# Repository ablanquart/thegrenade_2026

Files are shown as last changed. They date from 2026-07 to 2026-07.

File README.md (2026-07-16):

# The Grenade 2026 - An MRF101 40m AM Linear Amplifier
## USB-C Powered - 10W Carrier / 40W PEP - SMA Connectors

A bench-oriented 40-meter (7.0–7.3 MHz) AM linear amplifier built around a push-pull
pair of NXP **MRF101AN/MRF101BN** LDMOS transistors — powered from a standard 100 W
USB-C PD supply. Designed for experimental use under an FCC Part 5 license and
general amateur use on 40m.

**10 W carrier / 40 W PEP · 50 Ω in/out · runs from a laptop brick · absorptive harmonic termination**

## Features

- **USB-C powered**: negotiates 20 V / 5 A from any 100 W PD supply via a CH224K sink
  controller, then boosts to 48 V with an LM5122 synchronous boost converter.
- **Dual power path**: the boost output and a 48 V bench input are diode-ORed onto the
  main VDD rail — plug in whichever you have; both is fine.
- **Absorptive harmonic termination**: a high-pass diplexer branch dumps everything the
  output low-pass filter rejects into a 50 Ω / 6 W resistive load instead of reflecting
  it back into the PA drains. The transistors see a resistive load at all frequencies.
- **Interlocked bring-up**: the driver supply (LM2596HV buck) is enabled only after PD
  negotiation succeeds, or manually via a force-enable jumper (J5).
- **Status LEDs**: green = PD negotiated and boost alive; amber = main 48 V rail present.
- Temperature-tracked gate bias for the output pair.
- 7-element Chebyshev low-pass output filter, 7.5 MHz cutoff.

## Repository layout

```
├── mrf101_40m_pa_usbpd.kicad_pro   # KiCad project
├── mrf101_40m_pa_usbpd.kicad_sch   # Schematic
├── mrf101_40m_pa_usbpd.kicad_pcb   # Board (220 × 130 mm, 2-layer)
├── BOM_mrf101_40m_pa_usbpd.csv     # Bill of materials (grouped, with quantities)
├── fab_usbpd/                      # Gerbers, drill files, paste layers
├── docs/
│   ├── USER_GUIDE.md               # Setup and operation
│   └── SERVICE_MANUAL.md           # Theory of operation, component reference, test points
├── CHANGELOG.md
├── LICENSE                         # CERN-OHL-S v2
└── README.md
```

## Quick start

1. Bolt the board to a heatsink — the MRF101 pair **requires** one (TO-220 tab-down).
2. Connect a 50 Ω dummy load or antenna system to **J2 (RF OUT)**. Never key without a load.
3. Power: plug a 100 W USB-C PD supply into **J4**, or 48 V bench into **J3**.
4. Green LED (D7) = PD negotiated; amber LED (D8) = 48 V rail up.
5. Apply drive (≈1 W nominal) to **J1 (RF IN)**.

Full setup, bias adjustment, and first-power-up procedures are in
[docs/USER_GUIDE.md](docs/USER_GUIDE.md). Circuit theory, a complete component function
reference, and oscilloscope test points are in
[docs/SERVICE_MANUAL.md](docs/SERVICE_MANUAL.md).

## Bill of materials

The complete grouped BOM is [`BOM_mrf101_40m_pa_usbpd.csv`](BOM_mrf101_40m_pa_usbpd.csv).
Sourcing notes for the parts that matter:

| Part | Refs | Notes |
|---|---|---|
| MRF101AN + MRF101BN | Q1, Q2 | Buy the AN/BN *pair* — mirrored pinouts for layout symmetry. |
| CH224K | U3 | USB-PD sink controller, SSOP-10. |
| LM5122 | U4 | Sync boost controller, HTSSOP-20 (exposed pad). |
| LM2596HV-12 | U2 | HV variant is mandatory — input is 48 V. |
| BN-43-202, BN-43-3312 | T1, T2 | Binocular ferrite cores; wind per schematic. |
| 330 pF C0G **250 V** | C33, C34 | Diplexer series caps — voltage rating matters. |
| 390 nH, Q > 50 @ 20 MHz | L8 | 1812 air-core/ceramic, or wind 8t on a T37-6. |
| 100 Ω **3 W** 2512 | R34, R35 | The harmonic dump — do not substitute smaller. |
| USB-C 16-pin receptacle | J4 | Mid-mount, 5 A rated. |

## Regenerating fabrication files

With KiCad 10.x:

```sh
KCLI=/Applications/KiCad/KiCad.app/Contents/MacOS/kicad-cli   # adjust for your OS

$KCLI pcb export gerbers mrf101_40m_pa_usbpd.kicad_pcb -o fab_usbpd/
$KCLI pcb export drill   mrf101_40m_pa_usbpd.kicad_pcb -o fab_usbpd/ \
      --excellon-units mm --excellon-separate-th
```

Include the paste layers (F.Paste/B.Paste) if you're having a stencil made.

## Safety

This is a 40-watt RF power amplifier running on a 48-volt rail. Treat it accordingly:
hot heatsinks, RF voltage on exposed copper, and enough stored energy in the bulk
capacitors to be memorable. Operate into a proper load, within your license privileges,
and keep fingers off the output network while transmitting.

## License

This project is licensed under the **CERN Open Hardware Licence Version 2 —
Strongly Reciprocal (CERN-OHL-S v2)**. See [LICENSE](LICENSE) for the full text.

Copyright © 2026 Adam Blanquart

This source describes Open Hardware and is licensed under the CERN-OHL-S v2.
You may redistribute and modify this source and make products using it under
the terms of the CERN-OHL-S v2 (https://ohwr.org/cern_ohl_s_v2.txt).

This source is distributed WITHOUT ANY EXPRESS OR IMPLIED WARRANTY, INCLUDING
OF MERCHANTABILITY, SATISFACTORY QUALITY AND FITNESS FOR A PARTICULAR PURPOSE.
Please see the CERN-OHL-S v2 for applicable conditions.

Source location: https://github.com/ablanquart/thegrenade_2026/

As per CERN-OHL-S v2 section 4.1, any product you make from this design should
carry a reference back to the source location above.

---

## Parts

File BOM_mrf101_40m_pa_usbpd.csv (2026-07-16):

Refs | Value | Footprint | Qty
C1,C2,C7-C9,C14,C19,C22,C32 | 100nF | Capacitor_SMD:C_0805_2012Metric | 9
C3,C6 | 510pF | Capacitor_SMD:C_1206_3216Metric | 2
C4,C5 | 910pF | Capacitor_SMD:C_1206_3216Metric | 2
C10 | 1uF 100V | Capacitor_SMD:C_1206_3216Metric | 1
C11 | 100uF 63V | Capacitor_THT:CP_Radial_D8.0mm_P3.50mm | 1
C12 | 220uF 25V | Capacitor_THT:CP_Radial_D8.0mm_P3.50mm | 1
C13 | 10uF 25V | Capacitor_SMD:C_1206_3216Metric | 1
C20 | 10nF | Capacitor_SMD:C_0805_2012Metric | 1
C21 | 100pF | Capacitor_SMD:C_0805_2012Metric | 1
C23 | 2.2uF | Capacitor_SMD:C_1206_3216Metric | 1
C24,C25 | 22uF 63V | Capacitor_SMD:C_1210_3225Metric | 2
C26,C27 | 1000uF 63V | Capacitor_THT:CP_Radial_D10.0mm_P5.00mm | 2
C28 | 10uF 63V | Capacitor_SMD:C_1210_3225Metric | 1
C29,C30 | 22uF 25V | Capacitor_SMD:C_1210_3225Metric | 2
C31 | 1uF | Capacitor_SMD:C_0805_2012Metric | 1
C33,C34 | 330pF C0G 250V | Capacitor_SMD:C_1210_3225Metric | 2
D1 | SB560 (60V 5A) | Diode_SMD:D_SMC | 1
D3 | SS36 (60V) | Diode_SMD:D_SMA | 1
D4 | SB560 | Diode_SMD:D_SMC | 1
D6 | SMBJ24A | Diode_SMD:D_SMB | 1
D7 | green PD-OK | LED_SMD:LED_0805_2012Metric | 1
D8 | amber VDD | LED_SMD:LED_0805_2012Metric | 1
F1 | 6A | Fuse:Fuse_1812_4532Metric | 1
FLG1-FLG9 | PWR_FLAG |  | 9
J1 | SMA in | Connector_Coaxial:SMA_Molex_73251-1153_EdgeMount_Horizontal | 1
J2 | SMA out | Connector_Coaxial:SMA_Molex_73251-1153_EdgeMount_Horizontal | 1
J3 | 48V DC in | TerminalBlock:TerminalBlock_MaiXu_MX126-5.0-02P_1x02_P5.00mm | 1
J4 | USB-C PD 100W | Connector_USB:USB_C_Receptacle_HRO_TYPE-C-31-M-12 | 1
J5 | force-en | Connector_PinHeader_2.54mm:PinHeader_1x02_P2.54mm_Vertical | 1
L1,L3 | 1.51uH (19t T50-6) | Inductor_THT:L_Toroid_Vertical_L14.0mm_W6.3mm_P4.57mm_Pulse_A | 2
L2 | 1.67uH (20t T50-6) | Inductor_THT:L_Toroid_Vertical_L14.0mm_W6.3mm_P4.57mm_Pulse_A | 1
L4 | RFC 1mH | Inductor_THT:L_Toroid_Vertical_L14.0mm_W6.3mm_P4.57mm_Pulse_A | 1
L5 | 100uH | Inductor_SMD:L_12x12mm_H8mm | 1
L6 | 15uH 12A | Inductor_SMD:L_12x12mm_H8mm | 1
L7 | 2.2uH | Inductor_SMD:L_12x12mm_H4.5mm | 1
L8 | 390nH | Inductor_SMD:L_1812_4532Metric | 1
Q1 | MRF101AN | Package_TO_SOT_THT:TO-220-3_Horizontal_TabDown | 1
Q2 | MRF101BN | Package_TO_SOT_THT:TO-220-3_Horizontal_TabDown | 1
Q3 | 2N3904 | Package_TO_SOT_THT:TO-92_Inline | 1
Q4 | 2N3904 (heatsink) | Package_TO_SOT_THT:TO-92_Inline | 1
Q6 | 100V NFET | Package_TO_SOT_SMD:TO-252-2 | 1
Q7 | 100V NFET sync | Package_TO_SOT_SMD:TO-252-2 | 1
R1,R2 | 10 | Resistor_SMD:R_0805_2012Metric | 2
R3,R5,R13,R18,R20,R31 | 1k | Resistor_SMD:R_0805_2012Metric | 6
R4 | 4k7 | Resistor_SMD:R_0805_2012Metric | 1
R6,R7 | 330 | Resistor_SMD:R_2512_6332Metric | 2
R8-R10 | pad TBD | Resistor_SMD:R_0805_2012Metric | 3
R11 | 110 | Resistor_SMD:R_0805_2012Metric | 1
R12 | 8.87k | Resistor_SMD:R_0805_2012Metric | 1
R14 | 47 | Resistor_SMD:R_0805_2012Metric | 1
R19,R26,R32 | 10k | Resistor_SMD:R_0805_2012Metric | 3
R21,R22 | 100k | Resistor_SMD:R_0805_2012Metric | 2
R23 | 13k | Resistor_SMD:R_0805_2012Metric | 1
R24 | 40k2 (250kHz) | Resistor_SMD:R_0805_2012Metric | 1
R25 | 49k9 | Resistor_SMD:R_0805_2012Metric | 1
R27 | 590k | Resistor_SMD:R_0805_2012Metric | 1
R28 | 15k (50V) | Resistor_SMD:R_0805_2012Metric | 1
R29 | 5m | Resistor_SMD:R_2512_6332Metric | 1
R33 | 10k (FPWM) | Resistor_SMD:R_0805_2012Metric | 1
R34,R35 | 100 3W | Resistor_SMD:R_2512_6332Metric | 2
R36 | 6k8 | Resistor_SMD:R_0805_2012Metric | 1
R37 | 15k | Resistor_SMD:R_1206_3216Metric | 1
RV1 | 10k bias adj | Potentiometer_THT:Potentiometer_Bourns_3296W_Vertical | 1
T1 | 1:4 balun (BN-43-202) | linear_amp:Xfmr_Binocular_BN43-202_5pin | 1
T2 | 4:1 (BN-43-3312) | linear_amp:Xfmr_Binocular_BN43-3312_5pin | 1
U1 | PGA-103+ | linear_amp:PGA_103_MMIC | 1
U2 | LM2596HV-ADJ | Package_TO_SOT_THT:TO-220-5_Vertical | 1
U3 | CH224K | Package_SO:SSOP-10-1EP_3.9x4.9mm_P1mm_EP2.1x3.3mm | 1
U4 | LM5122 | Package_SO:HTSSOP-20-1EP_4.4x6.5mm_P0.65mm_EP3.4x6.5mm | 1

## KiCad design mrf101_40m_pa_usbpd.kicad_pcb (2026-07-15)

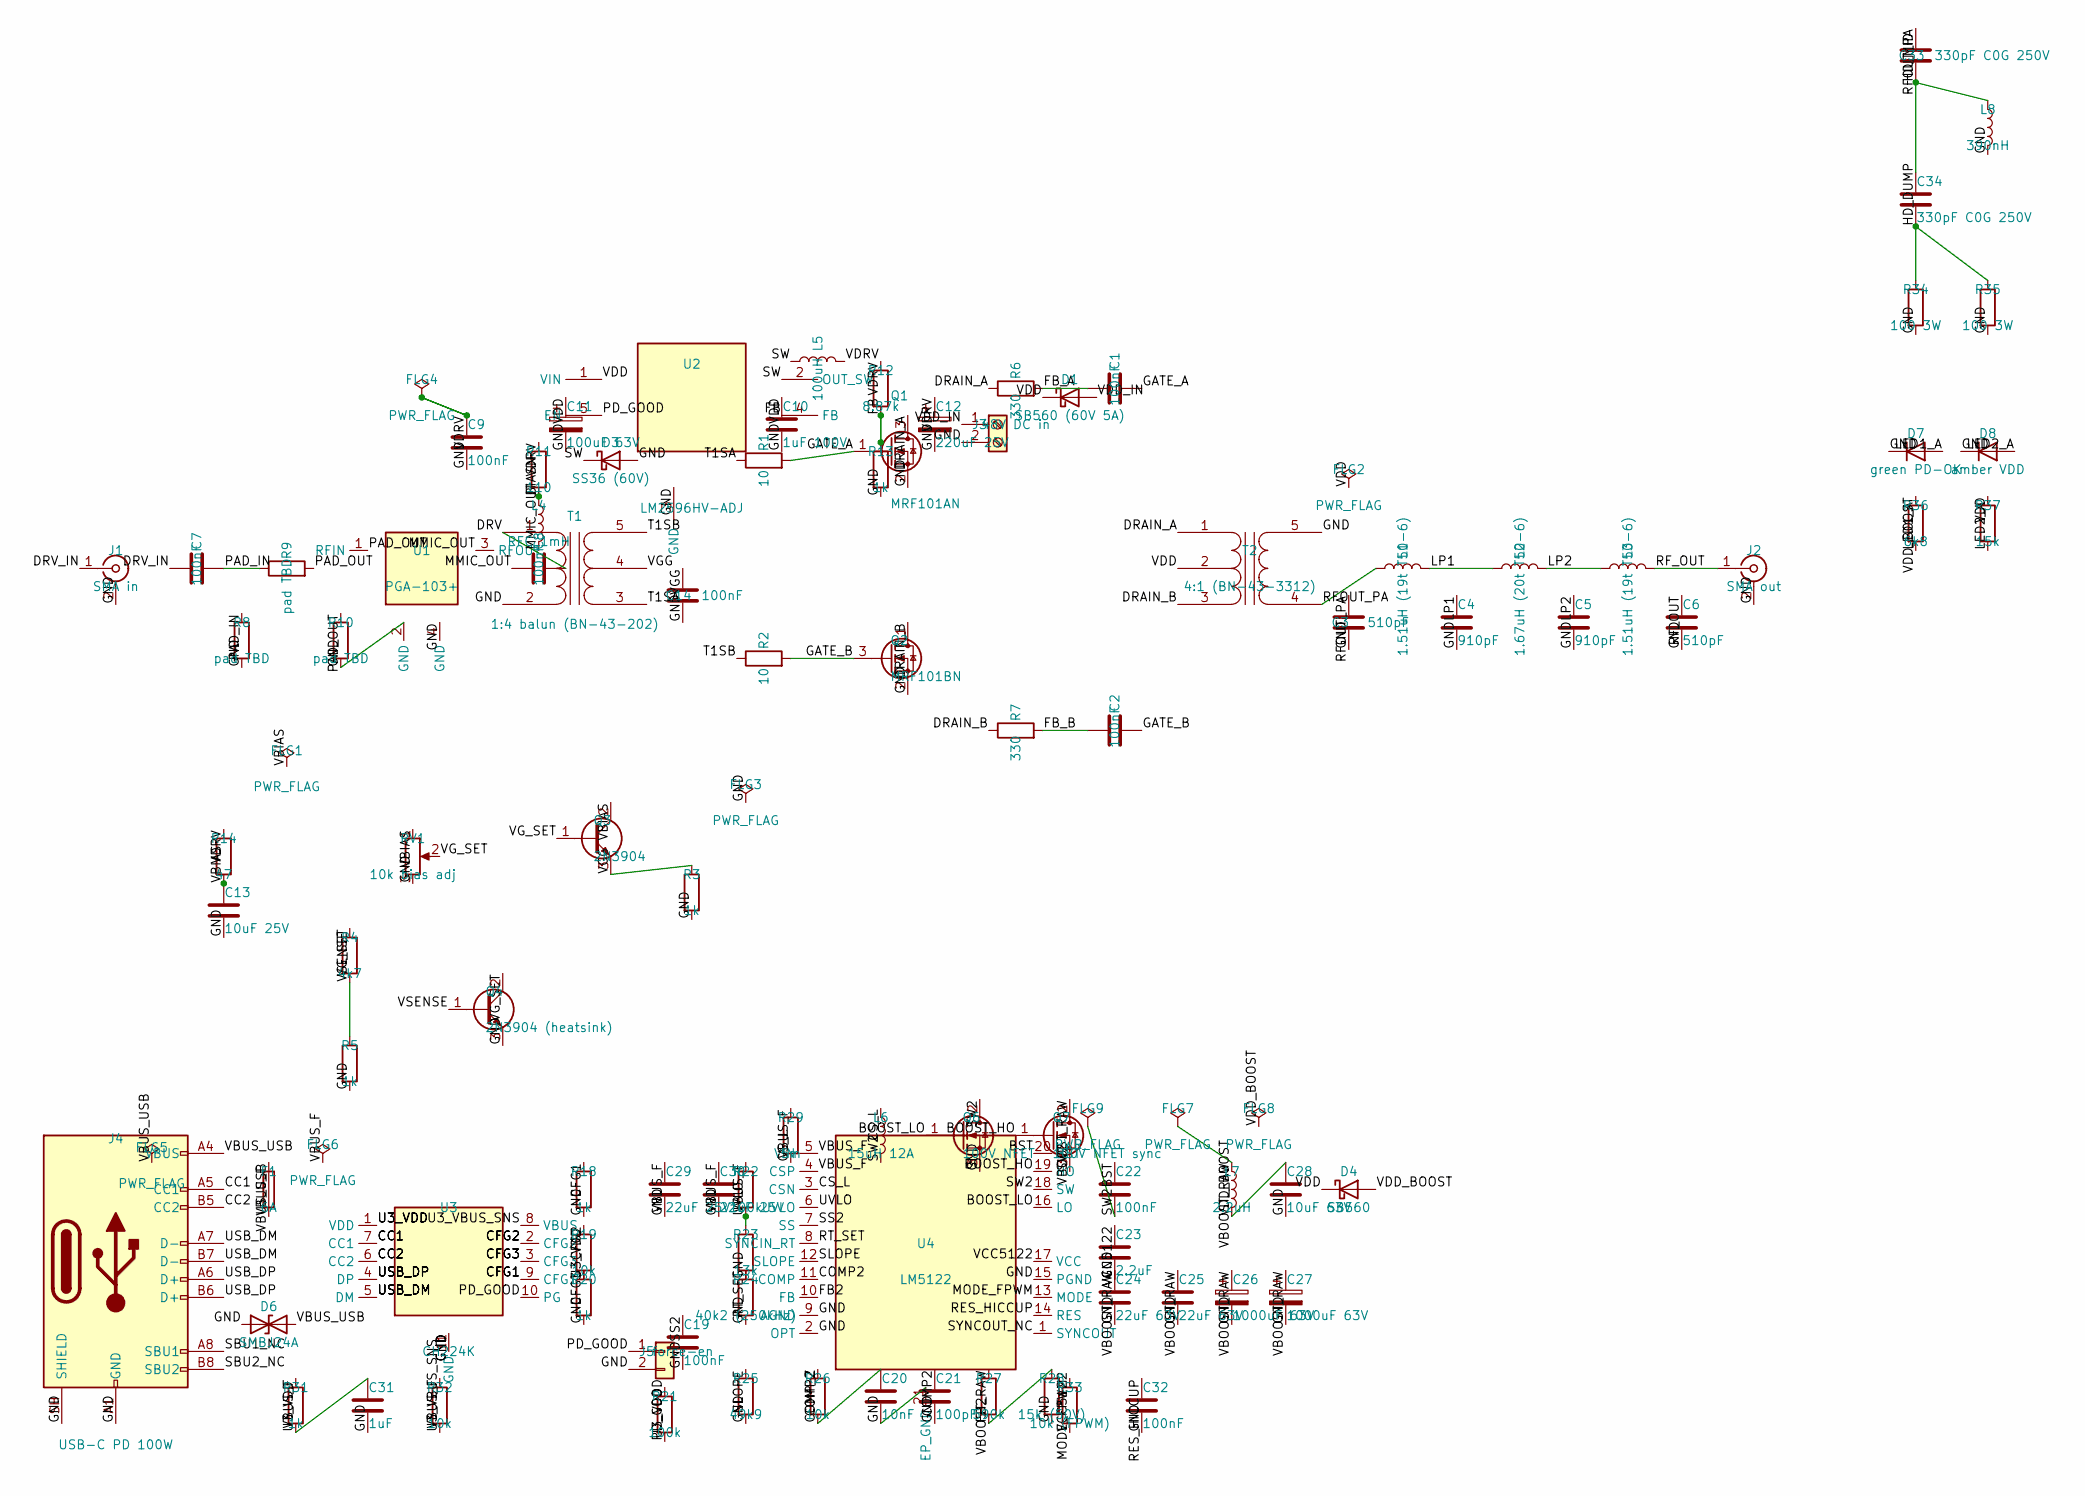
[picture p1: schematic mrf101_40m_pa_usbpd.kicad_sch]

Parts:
C1, C2, C7, C8, C9, C14, C19, C22, C32: 100nF; C_0805_2012Metric
C3, C6: 510pF; C_1206_3216Metric
C4, C5: 910pF; C_1206_3216Metric
C10: 1uF 100V; C_1206_3216Metric
C11: 100uF 63V; CP_Radial_D8.0mm_P3.50mm
C12: 220uF 25V; CP_Radial_D8.0mm_P3.50mm
C13: 10uF 25V; C_1206_3216Metric
C20: 10nF; C_0805_2012Metric
C21: 100pF; C_0805_2012Metric
C23: 2.2uF; C_1206_3216Metric
C24, C25: 22uF 63V; C_1210_3225Metric
C26, C27: 1000uF 63V; CP_Radial_D10.0mm_P5.00mm
C28: 10uF 63V; C_1210_3225Metric
C29, C30: 22uF 25V; C_1210_3225Metric
C31: 1uF; C_0805_2012Metric
C33, C34: 330pF C0G 250V; C_1210_3225Metric
D1: SB560 (60V 5A); D_SMC
D3: SS36 (60V); D_SMA
D4: SB560; D_SMC
D6: SMBJ24A; D_SMB
D7: green PD-OK; LED_0805_2012Metric
D8: amber VDD; LED_0805_2012Metric
F1: 6A; Fuse_1812_4532Metric
FLG1, FLG2, FLG3, FLG4, FLG5, FLG6, FLG7, FLG8, FLG9: PWR_FLAG
J1: SMA in; SMA_Molex_73251-1153_EdgeMount_Horizontal
J2: SMA out; SMA_Molex_73251-1153_EdgeMount_Horizontal
J3: 48V DC in; TerminalBlock_MaiXu_MX126-5.0-02P_1x02_P5.00mm
J4: USB-C PD 100W; USB_C_Receptacle_HRO_TYPE-C-31-M-12
J5: force-en; PinHeader_1x02_P2.54mm_Vertical
L1, L3: 1.51uH (19t T50-6); L_Toroid_Vertical_L14.0mm_W6.3mm_P4.57mm_Pulse_A
L2: 1.67uH (20t T50-6); L_Toroid_Vertical_L14.0mm_W6.3mm_P4.57mm_Pulse_A
L4: RFC 1mH; L_Toroid_Vertical_L14.0mm_W6.3mm_P4.57mm_Pulse_A
L5: 100uH; L_12x12mm_H8mm
L6: 15uH 12A; L_12x12mm_H8mm
L7: 2.2uH; L_12x12mm_H4.5mm
L8: 390nH; L_1812_4532Metric
Q1: MRF101AN; TO-220-3_Horizontal_TabDown
Q2: MRF101BN; TO-220-3_Horizontal_TabDown
Q3: 2N3904; TO-92_Inline
Q4: 2N3904 (heatsink); TO-92_Inline
Q6: 100V NFET; TO-252-2
Q7: 100V NFET sync; TO-252-2
R1, R2: 10; R_0805_2012Metric
R3, R5, R13, R18, R20, R31: 1k; R_0805_2012Metric
R4: 4k7; R_0805_2012Metric
R6, R7: 330; R_2512_6332Metric
R8, R9, R10: pad TBD; R_0805_2012Metric
R11: 110; R_0805_2012Metric
R12: 8.87k; R_0805_2012Metric
R14: 47; R_0805_2012Metric
R19, R26, R32: 10k; R_0805_2012Metric
R21, R22: 100k; R_0805_2012Metric
R23: 13k; R_0805_2012Metric
R24: 40k2 (250kHz); R_0805_2012Metric
R25: 49k9; R_0805_2012Metric
R27: 590k; R_0805_2012Metric
R28: 15k (50V); R_0805_2012Metric
R29: 5m; R_2512_6332Metric
R33: 10k (FPWM); R_0805_2012Metric
R34, R35: 100 3W; R_2512_6332Metric
R36: 6k8; R_0805_2012Metric
R37: 15k; R_1206_3216Metric
RV1: 10k bias adj; Potentiometer_Bourns_3296W_Vertical
T1: 1:4 balun (BN-43-202); Xfmr_Binocular_BN43-202_5pin
T2: 4:1 (BN-43-3312); Xfmr_Binocular_BN43-3312_5pin
U1: PGA-103+; PGA_103_MMIC
U2: LM2596HV-ADJ; TO-220-5_Vertical
U3: CH224K; SSOP-10-1EP_3.9x4.9mm_P1mm_EP2.1x3.3mm
U4: LM5122; HTSSOP-20-1EP_4.4x6.5mm_P0.65mm_EP3.4x6.5mm

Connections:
BIASN: L4.1, R11.2
BOOST_HO: Q7.1 (G), U4.19 (HO)
BOOST_LO: Q6.1 (G), U4.16 (LO)
BST: C22.1, U4.20 (BST)
CC1: J4.A5 (CC1), U3.7 (CC1)
CC2: J4.B5 (CC2), U3.6 (CC2)
CFG1: R18.1, U3.9 (CFG1)
CFG2: R19.1, U3.2 (CFG2)
CFG3: R20.1, U3.3 (CFG3)
COMP2: C21.1, R26.1, U4.11 (COMP)
COMP_Z: C20.1, R26.2
CS_L: L6.1, R29.2, U4.3 (CSN)
DRAIN_A: Q1.3 (D), R6.1, T2.1 (PR1)
DRAIN_B: Q2.1 (D), R7.1, T2.3 (PR2)
DRV: C8.2, T1.1 (AA)
DRV_IN: C7.1, J1.1 (In)
FB: R12.2, R13.1, U2.4 (FB)
FB2: R27.2, R28.1, U4.10 (FB)
FB_A: C1.1, R6.2
FB_B: C2.1, R7.2
GATE_A: C1.2, Q1.1 (G), R1.2
GATE_B: C2.2, Q2.3 (G), R2.2
GND: C3.2, C4.2, C5.2, C6.2, C9.2, C10.2, C11.2, C12.2, C13.2, C14.2, C19.2, C20.2, C21.2, C23.2, C24.2, C25.2, C26.2, C27.2, C28.2, C29.2, C30.2, C31.2, C32.2, D3.2 (A), D6.1 (A1), D7.1 (K), D8.1 (K), FLG3.1, J1.2 (Ext), J2.2 (Ext), J3.2, J4.A1 (GND), J4.A12 (GND), J4.B1 (GND), J4.B12 (GND), J4.SH (SHIELD), J5.2, L8.2, Q1.2 (S), Q2.2 (S), Q4.3 (E), Q6.3 (S), R3.2, R5.2, R8.2, R10.2, R13.2, R18.2, R20.2, R23.2, R24.2, R25.2, R28.2, R34.2, R35.2, RV1.3, T1.2 (AB), T2.5 (S2), U1.2 (GND), U1.4 (GND), U2.3 (GND), U3.11 (GND), U4.2 (OPT), U4.9 (AGND), U4.15 (PGND), U4.21 (EP_GND)
HD_DUMP: C34.2, R34.1, R35.1
HD_MID: C33.2, C34.1, L8.1
LED1_A: D7.2 (A), R36.2
LED2_A: D8.2 (A), R37.2
LP1: C4.1, L1.2, L2.1
LP2: C5.1, L2.2, L3.1
MMIC_OUT: C8.1, L4.2, U1.3 (RFOUT)
MODE_FPWM: R33.1, U4.13 (MODE)
PAD_IN: C7.2, R8.1, R9.1
PAD_OUT: R9.2, R10.1, U1.1 (RFIN)
PD_GOOD: J5.1, R21.2, U2.5 (EN), U3.10 (PG)
RES_HICCUP: C32.1, U4.14 (RES)
RFOUT_PA: C3.1, C33.1, L1.1, T2.4 (S1)
RF_OUT: C6.1, J2.1 (In), L3.2
RT_SET: R24.1, U4.8 (SYNCIN_RT)
SBU1_NC: J4.A8 (SBU1)
SBU2_NC: J4.B8 (SBU2)
SLOPE: R25.1, U4.12 (SLOPE)
SS2: C19.1, U4.7 (SS)
SW: D3.1 (K), L5.1, U2.2 (OUT_SW)
SW2: C22.2, FLG9.1, L6.2, Q6.2 (D), Q7.3 (S), U4.18 (SW)
SYNCOUT_NC: U4.1 (SYNCOUT)
T1SA: R1.1, T1.3 (SA)
T1SB: R2.1, T1.5 (SB)
U3_VBUS_SNS: R32.2, U3.8 (VBUS)
U3_VDD: C31.1, R19.2, R21.1, R31.2, U3.1 (VDD)
USB_DM: J4.A7 (D-), J4.B7 (D-), U3.5 (DM)
USB_DP: J4.A6 (D+), J4.B6 (D+), U3.4 (DP)
UVLO: R22.2, R23.1, U4.6 (UVLO)
VBIAS: C13.1, FLG1.1, Q3.2 (C), R14.2, RV1.1
VBOOST_RAW: C24.1, C25.1, C26.1, C27.1, FLG7.1, L7.1, Q7.2 (D), R27.1
VBUS_F: C29.1, C30.1, F1.2, FLG6.1, R22.1, R29.1, R31.1, R32.1, U4.4 (CSP), U4.5 (VIN)
VBUS_USB: D6.2 (A2), F1.1, FLG5.1, J4.A4 (VBUS), J4.A9 (VBUS), J4.B4 (VBUS), J4.B9 (VBUS)
VCC5122: C23.1, R33.2, U4.17 (VCC)
VDD: C10.1, C11.1, D1.1 (K), D4.1 (K), FLG2.1, R37.1, T2.2 (PM), U2.1 (VIN)
VDD_BOOST: C28.1, D4.2 (A), FLG8.1, L7.2, R36.1
VDD_IN: D1.2 (A), J3.1
VDRV: C9.1, C12.1, FLG4.1, L5.2, R11.1, R12.1, R14.1
VGG: C14.1, Q3.3 (E), R3.1, T1.4 (SC)
VG_SET: Q3.1 (B), Q4.2 (C), R4.1, RV1.2
VSENSE: Q4.1 (B), R4.2, R5.1

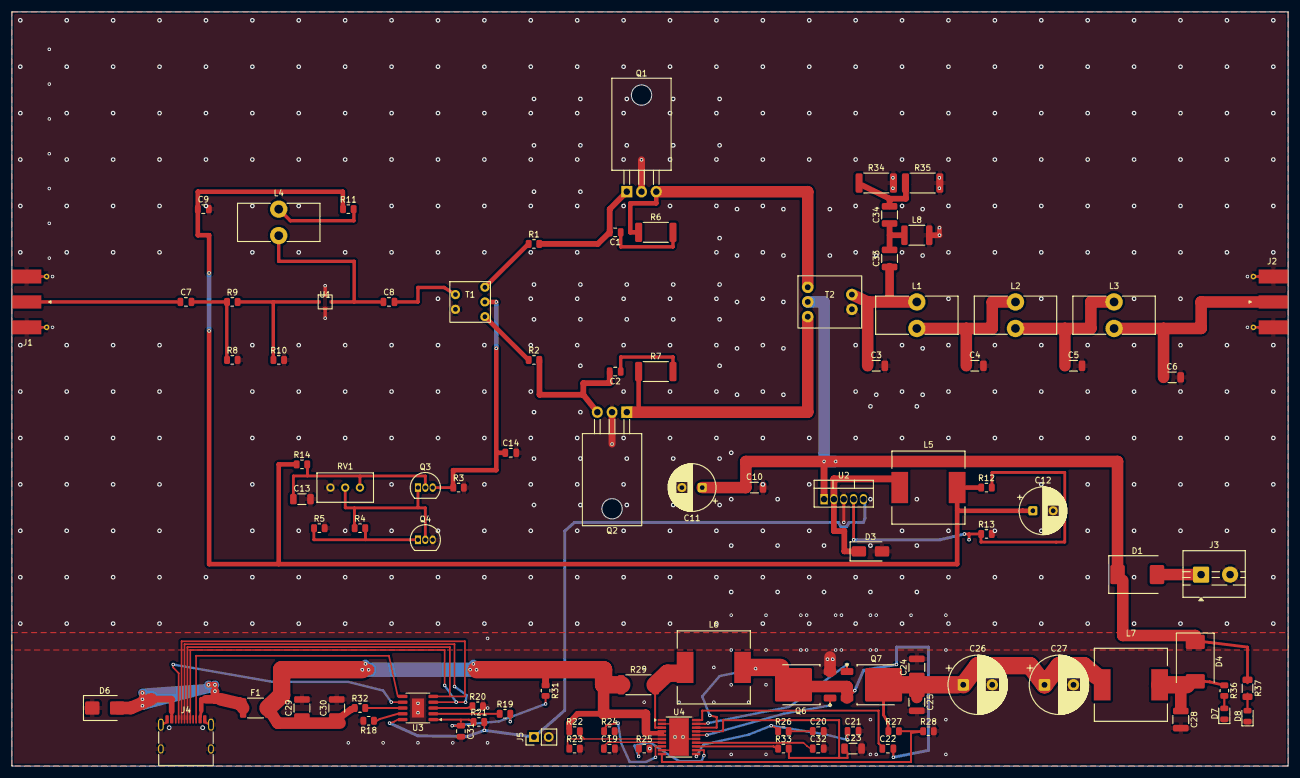
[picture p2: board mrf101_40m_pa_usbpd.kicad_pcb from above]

Board: 2 copper layers, 220.0 x 130.0 mm, 96 parts (0 on the bottom side), 61 nets.

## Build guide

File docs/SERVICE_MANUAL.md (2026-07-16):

# Service Manual — MRF101 40m AM Linear Amplifier

Board: `mrf101_40m_pa_usbpd` · 220 × 130 mm, 2-layer · Companion to
[USER_GUIDE.md](USER_GUIDE.md)

This manual describes what every functional block does, what the individual
components are for, where to put an oscilloscope probe, and what you should see
there. Reference designators follow the schematic; where an exact value matters,
confirm against the schematic rather than this text.

---

## 1. System overview

```
                    ┌──────────────── POWER ────────────────┐
J4 USB-C ─ D6 ─ F1 ─┤ U3 CH224K → 20V VBUS_F                │
                    │ U4 LM5122 boost → 48V VDD_BOOST ─ D4 ─┼─► VDD (48V)
J3 bench 48V ───────┤ ────────────────────────────── D1 ────┘
                    │ U2 LM2596HV buck  → 12V VDRV  (gated by PD_GOOD / J5)
                    └────────────────────────────────────────┘

J1 RF in ─ pad ─ driver ─ T1 1:4 ─ Q1/Q2 MRF101 push-pull ─ T2 4:1 ─┬─ LPF ─ J2 RF out
                                    (48V drain, IDQ 100 mA,          │
                                     temp-tracked bias)              └─ harmonic dump
                                                                        (C33/L8/C34 → R34‖R35)
```

Two independent stories share the board: the RF amplifier, and the power subsystem
that lets it run from a laptop brick. The seam between them is the VDD rail and the
PD_GOOD enable signal.

---

## 2. Power subsystem

### 2.1 USB-C input and PD negotiation

| Ref | Part | Function |
|---|---|---|
| **J4** | USB-C 16-pin receptacle | Power input. VBUS pads paralleled per side; outer pads and shield are grounded. |
| **D6** | SMB TVS diode | Clamps VBUS transients (hot-plug inductive spikes, misbehaving supplies) before anything downstream sees them. |
| **F1** | Fuse, 2512 | Series protection for the 20 V input path. If it opens, find out why before replacing. |
| **U3** | CH224K (SSOP-10) | USB-PD sink controller. Handles CC-line negotiation, requests 20 V, and asserts PD_GOOD (open-drain, active low) when the contract is granted. |
| **R18/R19/R20** | CFG straps | Program U3's voltage request to 20 V (CFG1/CFG2/CFG3 per the CH224K datasheet table). |
| **R31, C31** | 3.3 V rail RC | U3's internal LDO output (U3_VDD) decoupling and feed. |
| **R32** | VBUS sense | Feeds VBUS_F to U3's voltage-sense input so it can confirm the negotiated rail arrived. |
| **R21** | 10 k pull-up | Pulls PD_GOOD to U3_VDD; U3's open-drain output pulls it low on success. |
| **J5** | 2-pin jumper | Shorts PD_GOOD to ground manually — the bench-only force-enable. |
| **C29, C30** | 22 µF ceramics | VBUS_F input bulk for the boost converter. |

USB data lines (D+/D−) route to U3 for legacy BC1.2 detection only; they carry no
USB traffic. CC1/CC2 carry the actual PD negotiation.

### 2.2 Boost converter, 20 V → 48 V

| Ref | Part | Function |
|---|---|---|
| **U4** | LM5122 (HTSSOP-20) | Synchronous boost controller. |
| **R29** | Shunt, 2512 | Input-side current sense for U4's peak-current-mode control (CSP/CSN). |
| **L6** | Power inductor | The boost inductor — the energy-storage element. |
| **Q6** | NMOS, TO-252 | Low-side switch. Its drain tab **is** the SW2 switching node. |
| **Q7** | NMOS, TO-252 | High-side synchronous rectifier; source on SW2, drain to VBOOST_RAW. |
| **C22** | 100 nF | Bootstrap (BST) capacitor for the high-side gate driver, flying on SW2. |
| **C24, C25** | 10 µF ceramics | VBOOST_RAW output ceramics — first, low-ESR line of defense against switching ripple. |
| **C26, C27** | Electrolytics (radial) | Bulk output capacitance; holds the rail up under AM envelope current swings. |
| **L7** | Filter inductor | Second-stage LC with C28 — scrubs residual switching ripple off the rail before it reaches the PA. |
| **C28** | Output ceramic | Companion to L7. VDD_BOOST is measured here. |
| **R22, R23** | UVLO divider | Sets the input undervoltage lockout so the boost won't try to run from a half-negotiated rail. |
| **R24** | RT resistor | Sets switching frequency. |
| **C19** | Soft-start cap | Ramps output at startup; prevents inrush tripping the PD source. |
| **R25** | Slope comp | Slope-compensation programming. |
| **R26, C20, C21** | Compensation | Error-amplifier network on COMP (Type-II: R26+C20 series, C21 parallel). |
| **R27, R28** | Feedback divider | Sets the 48 V output: VBOOST_RAW → FB → GND. |
| **R33** | MODE strap | Selects forced-PWM operation. |
| **C32** | RES cap | Hiccup-mode restart timing. |
| **C23** | VCC bypass | U4's internal gate-drive LDO (≈7.5 V) decoupling. |

### 2.3 Rail ORing and the driver supply

| Ref | Part | Function |
|---|---|---|
| **D4** | SMC Schottky | ORs VDD_BOOST onto VDD. |
| **D1** | SMC Schottky | ORs the bench input (VDD_IN, via J3) onto VDD. Higher rail wins; neither back-feeds the other. |
| **U2** | LM2596HV-12 | 48 V → 12 V buck for VDRV, the driver-stage supply. Its EN pin is active-low, driven by PD_GOOD — so the driver (and therefore the whole RF chain) stays off until power is confirmed, or until J5 is jumpered. |
| **D7 + R36** | Green LED + 6.8 k | "PD OK" indicator, powered from VDD_BOOST: lights only when negotiation succeeded and the boost is delivering. |
| **D8 + R37** | Amber LED + 15 k | "VDD present" indicator on the ORed rail; lights from either power source (dimmer at 20 V-only fault conditions, ~3 mA at 48 V). |

---

## 3. RF chain

| Ref | Part | Function |
|---|---|---|
| **J1** | SMA edge-launch | 50 Ω drive input. |
| Input pad | Resistive attenuator | Sets drive level and presents a stable broadband source impedance to the driver (~0–3 dB as built). |
| Driver stage | — | Raises drive to the level the output pair needs; powered from VDRV (12 V). |
| **T1** | 1:4 on BN-43-202 | Input transformer/balun: splits drive into balanced push-pull gate drive and steps impedance down to the low gate impedance of the pair. |
| **Q1, Q2** | MRF101AN / MRF101BN | The output pair, TO-220 tab-down on the heatsink. The AN/BN complement exists purely for layout symmetry (mirrored pinout). 48 V drain, class AB. |
| Bias network (**Q4** et al.) | Temperature-tracked bias | A sensing transistor thermally coupled to the output devices servos the gate bias so IDQ (100 mA/device) holds as the heatsink warms, instead of running away. Adjust with the bias trimmer. |
| **T2** | 4:1 on BN-43-3312 | Output combiner: sums the push-pull drains and steps up to 50 Ω. Its output node is **RFOUT_PA**. |
| **L1…** + shunt Cs | 7-element Chebyshev LPF | 7.5 MHz cutoff. Passes 7 MHz; rejects the 2nd (14 MHz) and up by tens of dB. |
| **J2** | SMA edge-launch | 50 Ω output. |

### 3.1 The harmonic dump (absorptive termination)

A conventional LPF *reflects* the harmonics it rejects, and that reflected energy
arrives back at the drains with arbitrary phase — worsening IMD and inviting
instability. This board instead hangs a high-pass branch on RFOUT_PA, terminated in
a resistor, forming a first-order diplexer with the LPF:

| Ref | Value | Function |
|---|---|---|
| **C33, C34** | 330 pF C0G, 250 V | Series elements of a 3rd-order Butterworth high-pass, f_c ≈ 10 MHz. |
| **L8** | 390 nH | Shunt element of the high-pass. |
| **R34 ‖ R35** | 2 × 100 Ω, 3 W (= 50 Ω, 6 W) | The dump. Harmonic energy ends here as heat. |

At 7 MHz the branch looks like a high impedance and steals < 0.2 dB from the
fundamental. At 14 MHz and above it looks like 50 Ω, so the PA sees a resistive
load at every frequency of interest. Expected dissipation in normal operation is
well under 1 W; the 6 W rating is margin against mistuning and fault conditions.

---

## 4. Bias system

The output pair idles at **100 mA per device** (class AB), set by a trimmer and held
by the temperature-tracking network: the sense transistor (Q4), mounted in thermal
contact with the output devices' heatsink environment, has its own V_BE tempco
subtracted from the gate bias line, roughly cancelling the MRF101's threshold drift.

**Setting IDQ:** no drive, dummy load fitted, heatsink attached. Note supply current;
adjust the trimmer for +200 mA total (two devices). Re-verify after ten minutes of
idle warm-up — it should move only a few mA.

---

## 5. Protection & sequencing summary

1. **Hot-plug**: D6 clamps, F1 fuses.
2. **Negotiation**: U3 requests 20 V; nothing downstream runs until granted.
3. **Boost UVLO** (R22/R23): the LM5122 won't start on a sagging input.
4. **Soft-start** (C19): the 48 V rail ramps; no inrush trip.
5. **Driver interlock**: VDRV enabled by PD_GOOD (or J5).
6. **ORing** (D1/D4): dual supplies coexist safely.
7. **Absorptive output**: the PA is resistively loaded at all frequencies.

---

## 6. Oscilloscope test points

Ground your probe close to each measurement (short spring ground, not the alligator
tail, for anything above DC). ⚠ marks nodes carrying voltages or RF levels that
deserve respect. Values assume a 100 W PD source, dummy load, IDQ set.

### 6.1 Power subsystem

| # | Probe at | Net | Expect | Notes |
|---|---|---|---|---|
| TP1 | C29/C30 positive | VBUS_F | 20 V DC, <100 mV ripple | Brief 5 V interval at plug-in before negotiation completes is normal. |
| TP2 | C31 | U3_VDD | 3.3 V DC | CH224K internal LDO. |
| TP3 | J5 pin 1 | PD_GOOD | ≈0 V when negotiated; ≈3.3 V when not | Open-drain: watch it snap low ~500 ms after plug-in. |
| TP4 | **Q6 tab** ⚠ | SW2 | Rectangular wave, 0 ↔ ≈48 V, duty ≈ 58 %, at the R24-set switching frequency | The single most informative node in the boost. Clean fast edges with modest overshoot = healthy. Ringing >20 % of amplitude suggests layout/probing artifacts — reprobe with a spring ground before worrying. |
| TP5 | Q6 gate | BOOST_LO | 0 ↔ ≈7.5 V rectangular | Low-side gate drive from U4's VCC rail. |
| TP6 | Q7 gate ⚠ | BOOST_HO | Same shape, but riding on SW2 | High-side drive is SW-referenced — use a differential probe or interpret accordingly; a single-ended probe here shows SW2 plus the gate offset. |
| TP7 | C28 | VDD_BOOST | 48 V DC, ripple < ~50 mV after the L7/C28 filter | Sawtooth ripple at f_sw before L7 (probe C24/C25) is normal and larger. |
| TP8 | D4/D1 cathode side | VDD | 48 V DC | Dips of more than a volt or two on modulation peaks mean bulk capacitance or the PD source is struggling. |
| TP9 | U2 output | VDRV | 12 V DC | Only present when TP3 is low (or J5 jumpered). 52 kHz-ish LM2596 ripple is normal. |

### 6.2 RF chain

| # | Probe at | Net | Expect | Notes |
|---|---|---|---|---|
| TP10 | J1 side of the input pad | RF in | 7 MHz sine, ~20 Vpp at 1 W drive | Verifies the exciter before blaming the amplifier. |
| TP11 | Q1/Q2 gate (either) | Gate bias | ≈2–3 V DC + drive superimposed | DC level is the bias servo output; both gates should match within tens of mV. |
| TP12 | C33's tap trace / L1 pad ⚠ | RFOUT_PA | 7 MHz, ≈32 Vpk carrier, ≈63 Vpk at PEP crest (10 W/40 W into 50 Ω) | Pre-filter node — visible harmonic content and flat-topping on peaks is *expected here*; the LPF cleans it. Use a ×10 probe minimum. |
| TP13 | J2 (through a power attenuator!) ⚠ | RF out | Clean 7 MHz sine, same amplitudes | **Never** probe J2 directly at power — use a tap or attenuator. Compare spectral purity against TP12 to see the filter earn its keep. |
| TP14 | Across R34/R35 | HD_DUMP | Small residual RF, typically < 5 V RMS | **The built-in harmonic meter.** P_dump = V_RMS² / 50. Under 0.5 W is healthy. A sudden rise here is your earliest warning of bias drift, parasitic oscillation, or filter damage — before anything smokes. |

### 6.3 Diagnostic patterns worth knowing

- **SW2 stuck low, no green LED:** boost never started — check UVLO divider values,
  VBUS_F actually at 20 V, C19 not shorted.
- **SW2 switching in bursts:** hiccup mode — output overloaded or shorted; also the
  signature of an undersized PD source current-limiting.
- **TP14 grows with heatsink temperature:** bias tracking failing (Q4 thermal contact),
  crossover distortion rising as IDQ falls.
- **TP14 shows non-harmonic frequencies:** parasitic oscillation — stop transmitting,
  check gate resistors and T1/T2 integrity.
- **TP12 asymmetric top/bottom:** push-pull imbalance — one device biased off or dead;
  compare TP11 on both gates.

---

## 7. Troubleshooting matrix

| Symptom | Check, in order |
|---|---|
| Dead on USB-C | Cable (needs e-marked 5 A), F1 continuity, D6 not shorted, TP1 |
| TP1 = 5 V, never 20 V | CC lines / CFG straps R18–R20, source's 20 V capability, TP2 present |
| TP1 = 20 V, TP7 dead | UVLO (R22/R23), TP4 activity, U4 VCC at C23, FB divider R27/R28 |
| TP7 = 48 V, TP9 dead | TP3 state, J5 if bench-only, U2 itself |
| All rails up, no output | TP10 (drive present?), TP11 (bias?), driver stage on VDRV |
| Low gain / distortion | IDQ setting, input pad value, supply sag at TP8 under drive |
| Dump resistors hot | §6.3 patterns — bias, oscillation, LPF |
| Blows F1 repeatedly | D6 shorted, C29/C30 shorted, Q6 failed short (SW2 reads 0 Ω to GND) |

---

## 8. Fabrication & rework notes

- 2-layer, 1 oz copper. B.Cu is a ground plane with a handful of signal crossings
  (gate drives, USB pair, PD_GOOD run, small-signal reroutes) — if you cut the plane
  during rework near U4 or the USB section, check those.
- The MRF101 tabs and the TO-252 FETs are the significant thermal masses for rework:
  preheat.
- U3 (0.5 mm pitch) and U4 (0.65 mm pitch, exposed pad) are the fine-pitch parts;
  everything else is hand-iron friendly.
- Known-accepted DRC baseline: U2's footprint annular/clearance quirks, U4's
  footprint-intrinsic 0.19 mm pad-gap flags, SMA edge-launch copper (deliberate),
  and same-net zone overlaps at the y = 107 mm seam. Roughly 60 items total; anything
  *beyond* that set after a modification deserves a look.

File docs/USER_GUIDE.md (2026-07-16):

# User's Guide — MRF101 40m AM Linear Amplifier

This guide covers setup and day-to-day operation. For circuit theory, component
functions, and test points, see [SERVICE_MANUAL.md](SERVICE_MANUAL.md).

## 1. What you need

- A **heatsink** for the MRF101 pair (Q1/Q2, TO-220 tab-down). At 10 W carrier AM the
  devices dissipate continuously — do not run the board without one, even briefly.
  Use thermal compound; insulating washers are not required (tabs are source/ground —
  verify against your heatsink grounding scheme before assuming).
- A **50 Ω load**: dummy load for testing, or a matched antenna system. The amplifier
  must never be keyed without a load on J2.
- **Power**, one or both of:
  - A **USB-C PD supply rated 100 W (20 V / 5 A)**. Lower-rated supplies (e.g. 65 W)
    will negotiate but will current-limit under full drive — fine for receive-level
    testing, not for transmitting.
  - A **48 V bench supply**, 2 A or better, into J3.
- A **drive source**: approximately 1 W of clean 7 MHz drive at J1 produces full output.
  An input attenuator pad is provided on-board for level matching.

## 2. Connections

| Connector | Function |
|---|---|
| **J1** | RF input, SMA, 50 Ω |
| **J2** | RF output, SMA, 50 Ω — load goes here, always |
| **J3** | 48 V bench supply input |
| **J4** | USB-C power input (PD, 20 V negotiated) |
| **J5** | Driver-supply force-enable jumper (see §5) |

Both power inputs may be connected simultaneously; Schottky ORing diodes (D1, D4)
select whichever rail is higher and prevent back-feeding.

## 3. Status LEDs

| LED | Color | Meaning when lit |
|---|---|---|
| **D7** | Green | USB-PD negotiation succeeded **and** the 48 V boost converter is running |
| **D8** | Amber | The main 48 V rail (VDD) is up — from either the boost or the bench input |

Normal USB-C operation: both LEDs lit. Bench-only operation: amber only.
Green off with USB-C connected means PD negotiation failed — see §7.

## 4. First power-up (do this once per new build)

Work through this before ever applying RF drive:

1. **Visual inspection.** Solder bridges around U3 (SSOP-10) and U4 (HTSSOP-20) are the
   most likely build faults. Check the electrolytics (C26, C27) for polarity.
2. **Resistance checks, power off.** VDD to GND and VBUS_F to GND should both read
   high (>1 kΩ rising as caps charge on the meter). A dead short here means stop.
3. **USB power, no drive, no load required yet.** Plug in a PD supply. Within about a
   second you should get: green LED, amber LED. Verify with a meter:
   - 20 V on VBUS_F (across C29/C30)
   - 48 V on VDD_BOOST (across C28)
   - 48 V on VDD
   - 12 V on VDRV (U2 output) — this rail only comes up when PD_GOOD is asserted
   - 3.3 V on U3_VDD (across C31)
4. **Set the quiescent bias.** With a dummy load on J2, no drive, and the heatsink
   attached: monitor supply current and adjust the bias trimmer for **100 mA of drain
   current per device** (200 mA total increase over the no-bias baseline). The bias
   network is temperature-compensated; let the heatsink warm and confirm IDQ stays
   put. See the service manual §4 for the bias network description.
5. **Low drive test.** Apply ~100 mW of 7.0–7.3 MHz drive. Confirm output on a scope
   or power meter, then bring drive up gradually while watching supply current and
   output power. Full drive (~1 W) should yield ≈10 W of carrier.

## 5. The J5 jumper (force-enable)

The driver supply (U2, 12 V) is normally enabled by the CH224K's power-good signal —
the amplifier stays quiet until USB-PD negotiation has actually delivered 20 V.

When running from the **bench supply only** (nothing on USB-C), there is no PD_GOOD,
so fit a **jumper across J5** to enable the driver rail manually. Remove it when
running from USB-C if you want the negotiation interlock back (recommended).

## 6. Operating notes

- **Duty cycle.** AM carrier means continuous dissipation. Watch heatsink temperature
  during long transmissions; the MRF101 is rugged but not immortal.
- **Harmonics.** The output filter plus the absorptive dump network keep harmonic
  output clean and keep the PA stable into imperfect loads. The dump resistors
  (R34/R35, near the output filter) run warm in normal operation — a few degrees
  above ambient. If they run **hot**, something is wrong upstream (see the service
  manual troubleshooting table).
- **SWR.** The amplifier tolerates moderate mismatch thanks to the absorptive
  termination, but it is not protected against gross faults. Aim for < 2:1.
- **PD supplies.** Any USB-C source that advertises a 20 V PDO works. Sources that
  top out at 15 V will light neither the boost nor the green LED — the CFG straps
  request 20 V specifically and the design assumes it.

## 7. Quick troubleshooting

| Symptom | Likely cause |
|---|---|
| No LEDs on USB-C | Bad cable (must be a full-featured/e-marked cable for 5 A), F1 fuse open, TVS D6 failed short |
| Amber on, green off (USB-C) | PD negotiation failed: 5 V-only or 15 V-max source, or CC-line issue |
| LEDs on, no RF output | No drive at J1; J5 jumper missing on bench-only power; VDRV rail down; bias mis-set |
| Output low and distorted | IDQ set too low; drive overloading the input pad; supply current-limiting (undersized PD source) |
| Dump resistors hot | Excess harmonic energy: check bias (crossover distortion), check for parasitic oscillation, verify LPF assembly |
| Boost whines / green LED flickers | PD source current-limiting under load — use a genuine 100 W supply |

Deeper diagnosis with an oscilloscope: service manual §6.

## 8. Care and feeding

Keep the heatsink interface clean, keep RF connectors torqued, and re-check IDQ after
the first few thermal cycles of a new build. The bulk electrolytics are the only
components with a wear-out mechanism; everything else should outlive your interest
in 40 meters, which is saying something.

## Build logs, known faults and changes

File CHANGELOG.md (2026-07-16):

# Changelog

## rev A (2026-07) — initial public release

USB-C powered 40m AM linear amplifier, 10 W carrier / 40 W PEP.

### RF section
- MRF101AN/BN push-pull output pair, 48 V drain, temperature-tracked bias
  (IDQ 100 mA/device).
- 1:4 input transformer (BN-43-202), 4:1 output combiner (BN-43-3312).
- 7-element Chebyshev low-pass output filter, 7.5 MHz cutoff.
- Absorptive harmonic termination: 3rd-order Butterworth high-pass
  (C33/L8/C34, f_c ≈ 10 MHz) into a 50 Ω / 6 W dump (R34‖R35) hung on the
  pre-filter node — the PA sees a resistive load at all frequencies.

### Power section
- USB-C input (J4) with TVS clamp (D6) and fuse (F1).
- CH224K PD sink controller (U3) configured for 20 V, with CC/DP/DM fanout
  and PD_GOOD interlock.
- LM5122 synchronous boost (U4, Q6/Q7, L6, R29 sense): 20 V → 48 V, with
  L7/C28 post-filter.
- Schottky ORing (D1/D4) of the boost rail against a 48 V bench input (J3).
- Driver-supply interlock: LM2596HV (U2, 12 V VDRV) enabled by PD_GOOD;
  J5 force-enable jumper for bench-only operation.
- Status LEDs: D7 (green, PD-OK) and D8 (amber, VDD present).

### Board
- 220 × 130 mm, 2-layer, 1 oz.
- DRC clean to documented baseline (see SERVICE_MANUAL.md §8); connectivity
  verified including ratsnest.

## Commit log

2026-07-15 Initial Upload of v1.0.0
    [mrf101_40m_pa_usbpd.kicad_pcb, mrf101_40m_pa_usbpd.kicad_sch]
2026-07-15 Uploading Gerbers for version 1.0.0
    [mrf101_40m_pa_usbpd-B_Courtyard.gbr, mrf101_40m_pa_usbpd-B_Cu.gbl, mrf101_40m_pa_usbpd-B_Fab.gbr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]
